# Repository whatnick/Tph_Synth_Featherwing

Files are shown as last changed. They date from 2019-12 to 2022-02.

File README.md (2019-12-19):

# 3-Phase ELV synthesizer using DAC and Opamps

This is a FeatherWing ideally used with Teensy 3.2/4.0 to drive a high-speed DAC with 
filtering and signal conditioning using Opamps.

## Features :
- 50/60 Hz Frequency Selector ( Possibly just do it in software).
- Pot driven voltage Setting by controlling inverting-Opamp gain.
- Modified-Howland current source to simulate current clamp output.
- Pot driven current source using a tapped potentiometer attached to DAC output.
- ±5v RMS output using dual-rail Opamp mode - [OPA4170AIPW](https://au.element14.com/texas-instruments/opa4170aipw/op-amp-quad-rro-1mhz-14tssop/dp/2095843) or [LM324PWR](https://au.element14.com/texas-instruments/lm324pwr/ic-op-amp-1-2mhz-0-5v-us-tssop/dp/2342289)
- Dual-voltage rail generation using [LM2663](https://au.element14.com/texas-instruments/lm2663mx-nopb/dc-dc-charge-pump-inverting-soic/dp/3008264) to flip 5v input to -5v.
- Boost-converter to push battery voltage (4.2v-3.7v) to 5v for non-USB power mode using [PAM2401](https://au.mouser.com/datasheet/2/115/PAM2401-347378.pdf).
- I2C DAC circuit to generate plausible phase shifted sine-wave, like in my [DIYODE 
Article](https://diyodemag.com/features/safe_3-phase_generator) using [MCP4728](https://au.element14.com/microchip/mcp4728-e-un/ic-dac-12bit-quad-10msop/dp/1800217).
- Fully open-source schematic/pcb in KiCAD.
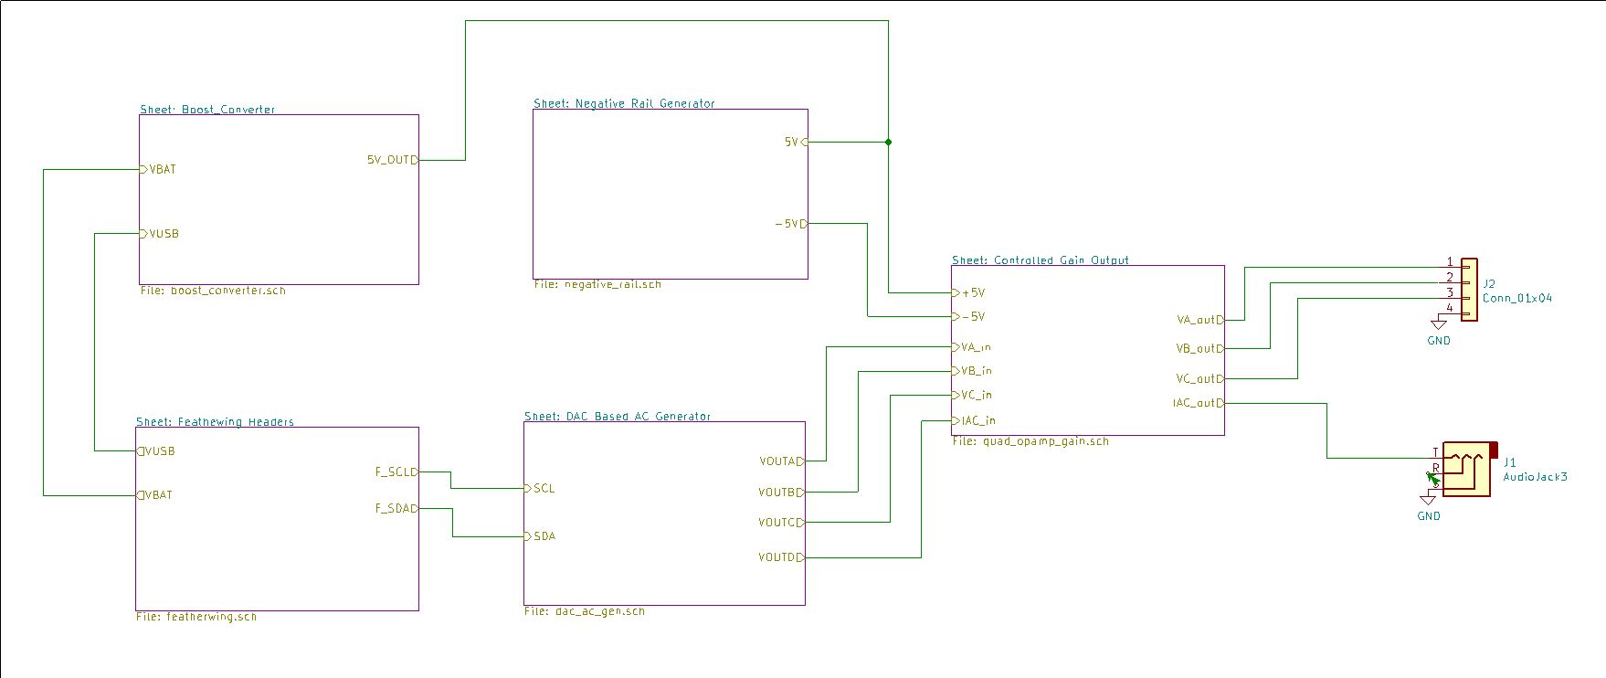
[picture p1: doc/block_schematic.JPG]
Schematic Screenshot


## Roadmap Features :
- Experiment with power Opamps or eBay power amplifiers to output real 240v rail-to-rail swings.
- Experiment with power path IC's to manage supply from USB vs Battery. Particulary [LTC4412](https://www.analog.com/media/en/technical-documentation/data-sheets/4412fb.pdf) is of interest at high-power modes due to losses in [Schottky diodes](https://www.analog.com/media/en/technical-documentation/product-information/Battery_Management_Soulutions_PowerPath.pdf) and LV usage with buck-converters from 240v.
- Add I2C digital pots instead of physical pots.

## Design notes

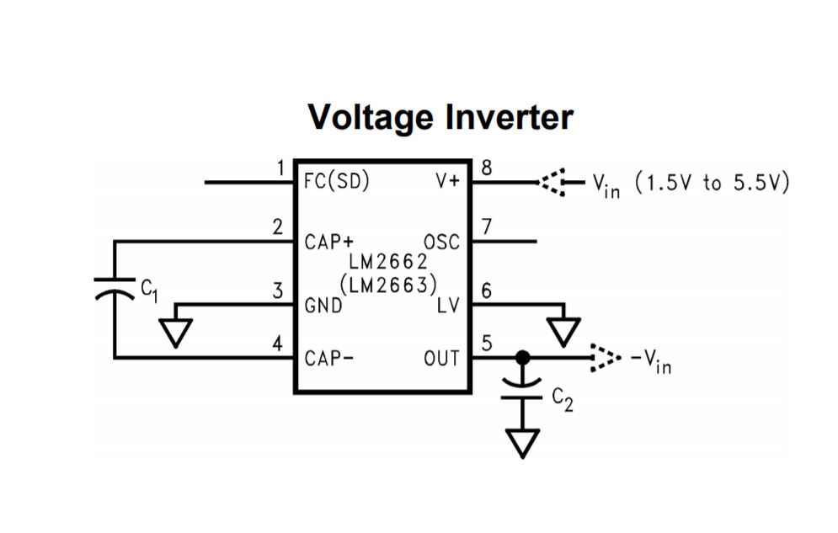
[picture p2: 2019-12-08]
doc/voltage_inverter.JPG

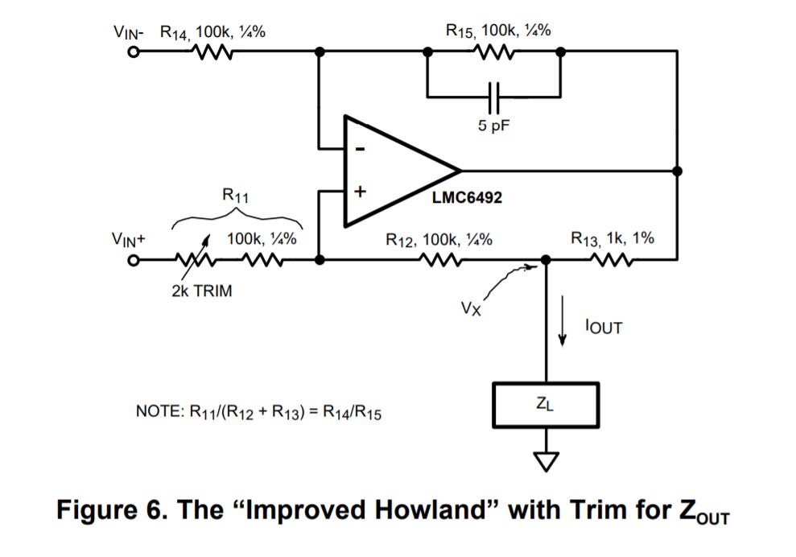
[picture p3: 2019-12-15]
doc/howland_current_pump.JPG

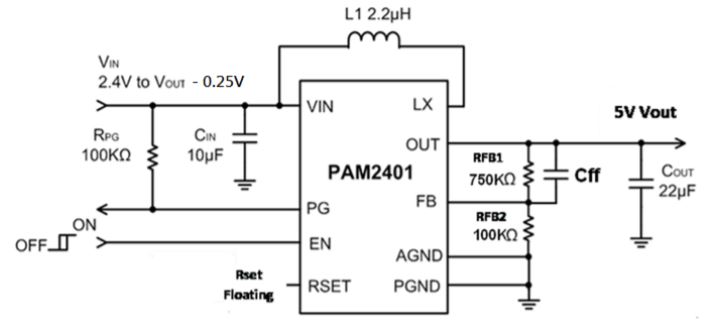
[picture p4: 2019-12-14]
doc/boost_converter.JPG

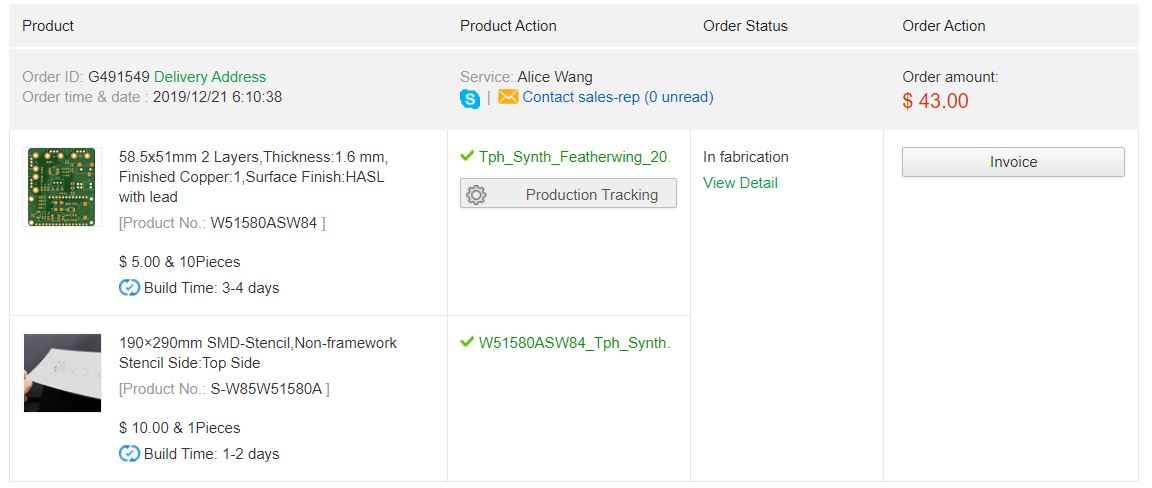
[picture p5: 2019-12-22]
doc/manf_log/pcbway_r0.1.JPG

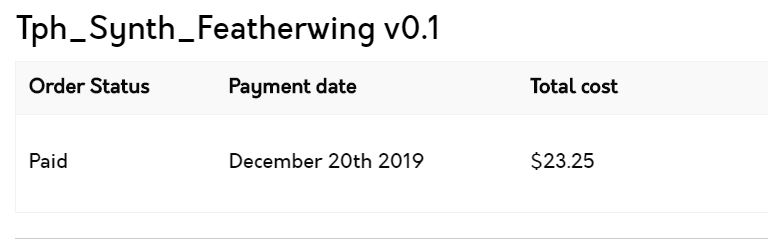
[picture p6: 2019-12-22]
doc/manf_log/oshpark_r0.1.JPG

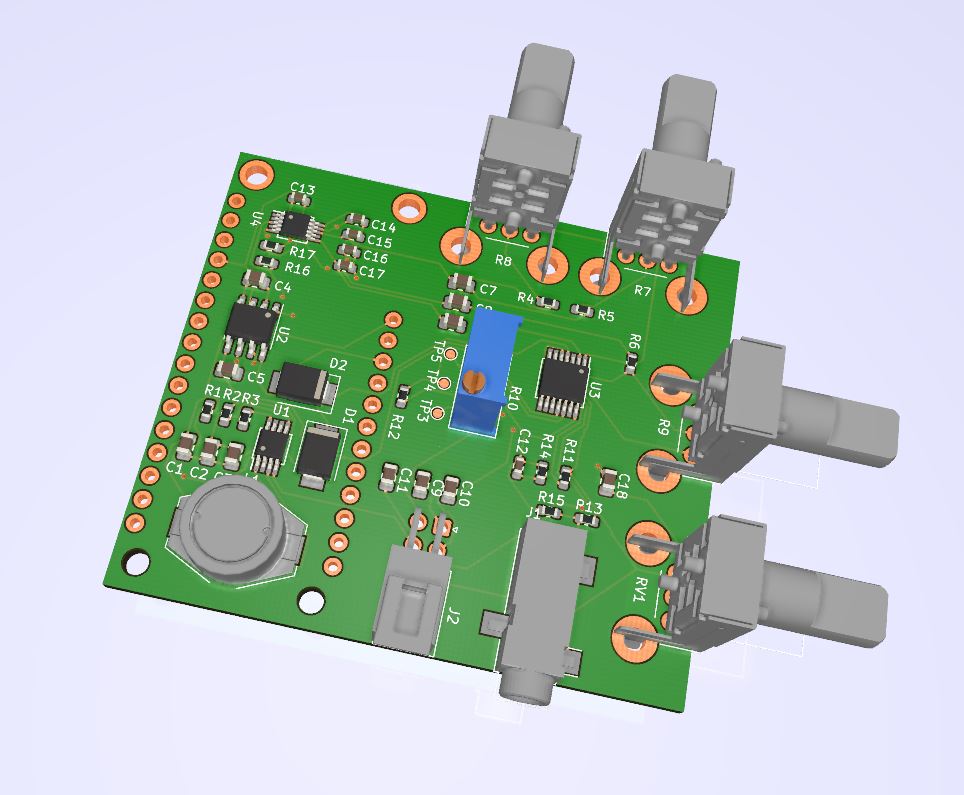
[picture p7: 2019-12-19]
doc/pcb_screenshot.JPG

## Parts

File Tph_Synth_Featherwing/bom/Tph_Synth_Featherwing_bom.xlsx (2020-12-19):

References | manf# | Value | Footprint | Quantity
C1, C2, C3 | C2012JB1V226M125AC | 22u | C_0805_2012Metric | 3
C13, C14, C15, C16, C17 | GCM188L81H104KA57D | 100n | C_0603_1608Metric | 5
C12 | GJM0335C1E5R0BB01D | 5p | C_0603_1608Metric | 1
C4, C5, C6, C7, C8, C9, C10, C11, C18 | GMK212BBJ106MG-T | 10u | C_0805_2012Metric | 9
R15 | CRT0603-FY-1001ELF | 1k / 1% | R_0603_1608Metric | 1
R7, R8, R9 | PTV09A-2020F-B104 | 100k var | Potentiometer_Bourns_PTV09A-2_Single_Horizontal | 3
R10 | PV36W202C01B00 | 2k Trim | Potentiometer_Bourns_3296W_Vertical | 1
R3 | RC0603FR-07100KL | 100k | R_0603_1608Metric | 1
R16, R17 | RC0603FR-072K2L | 2.2k | R_0603_1608Metric | 2
R2 | RC0603FR-07750KL | 750k | R_0603_1608Metric | 1
R11, R12, R13, R14 | RT0603CRE07100KL | 100k / 0.25% | R_0603_1608Metric | 4
R1, R4, R5, R6 | RT0603FRD0710KL | 10k | R_0603_1608Metric | 4
L1 | SRR1005-2R2M | 2.2uH/3A | L_Bourns-SRR1005 | 1
D1, D2 | B330B-13-F | D_Schottky | D_SMB | 2
U2 | LM2663MX/NOPB | LM2663M | SOIC-8_3.9x4.9mm_P1.27mm | 1
U3 | LM324PWR | Opamp_Quad_Generic | TSSOP-14_4.4x5mm_P0.65mm | 1
U4 | MCP4728-E/UN | MCP4728 | MSOP-10_3x3mm_P0.5mm | 1
U1 | PAM2401SCADJ | PAM2401SCADJ | MSOP-8_3x3mm_P0.65mm | 1
MS1 | 3200 | ADAFRUIT_FEATHERWING | adafruit_featherwing | 1
RV1 | PTV09A-2020F-B104 | 100k POT | Potentiometer_Bourns_PTV09A-2_Single_Horizontal | 1
J2 | 105314-1204 | Conn_01x04 | Molex_Nano-Fit_105314-xx04_2x02_P2.50mm_Horizontal | 1
J1 | SJ-3523-SMT-TR | AudioJack3 | Jack_3.5mm_CUI_SJ-3523-SMT_Horizontal | 1
J3 | SM04B-SRSS-TB(LF)(SN) | Conn_01x04 | JST_SH_SM04B-SRSS-TB_1x04-1MP_P1.00mm_Horizontal | 1

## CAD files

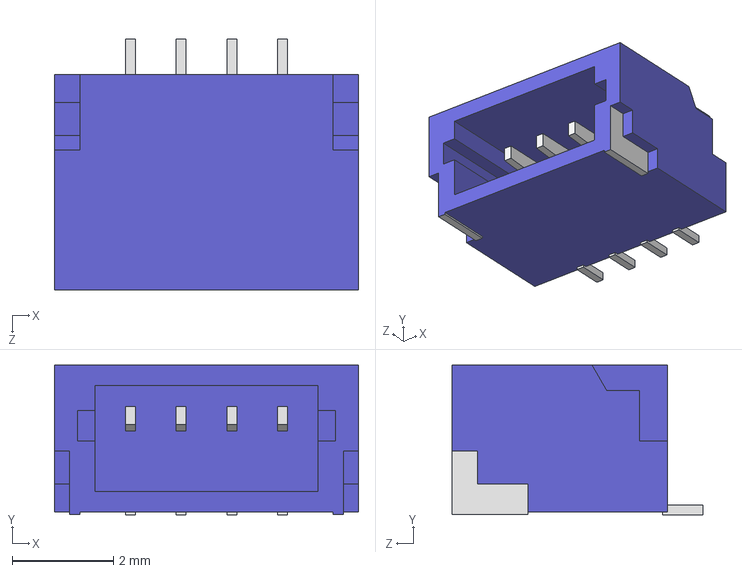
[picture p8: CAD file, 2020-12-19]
Tph_Synth_Featherwing/3dmodels/SM04B-SRSS-TB.STEP
6.00 x 2.96 x 4.95 mm

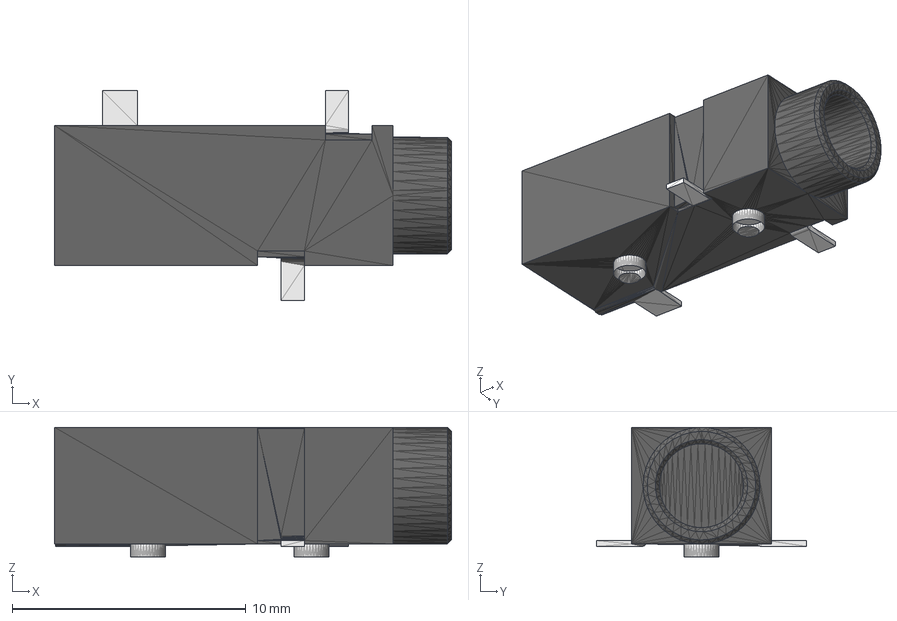
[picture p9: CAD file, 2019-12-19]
Tph_Synth_Featherwing/3dmodels/CUI_SJ-3523.step
17.0 x 9.00 x 5.80 mm

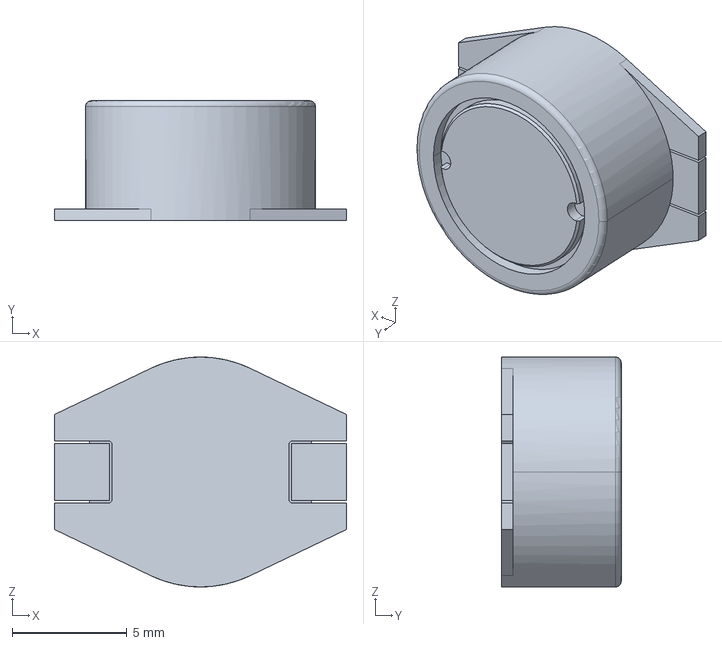
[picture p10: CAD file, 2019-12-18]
Tph_Synth_Featherwing/3dmodels/srr1005.stp
12.7 x 5.20 x 10.0 mm

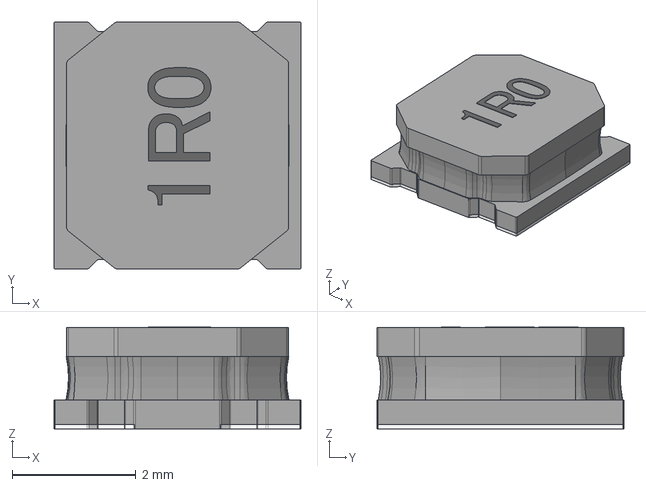
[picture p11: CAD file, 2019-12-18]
Tph_Synth_Featherwing/3dmodels/srn4018.stp
4.00 x 4.00 x 1.65 mm

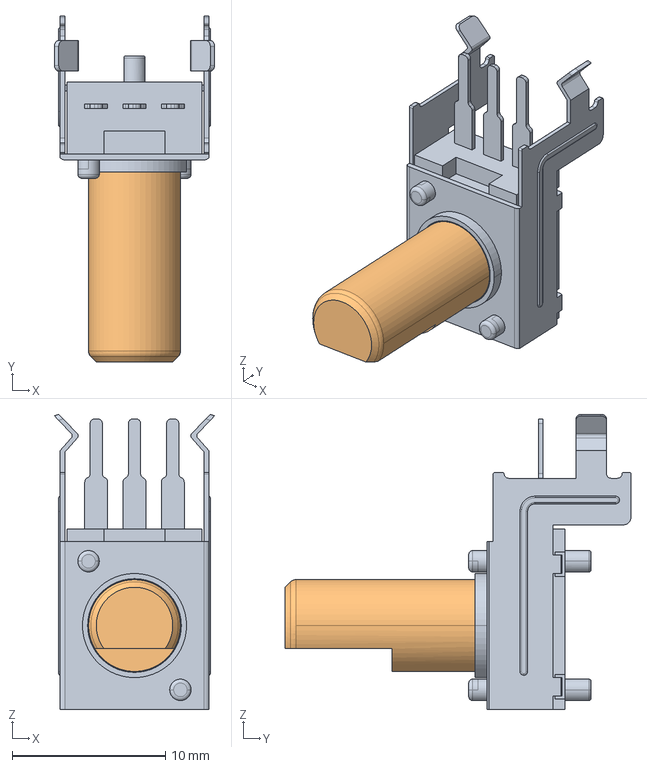
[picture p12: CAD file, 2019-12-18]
Tph_Synth_Featherwing/3dmodels/ptv09a-2x20f-xxxx.stp
10.5 x 22.6 x 19.3 mm

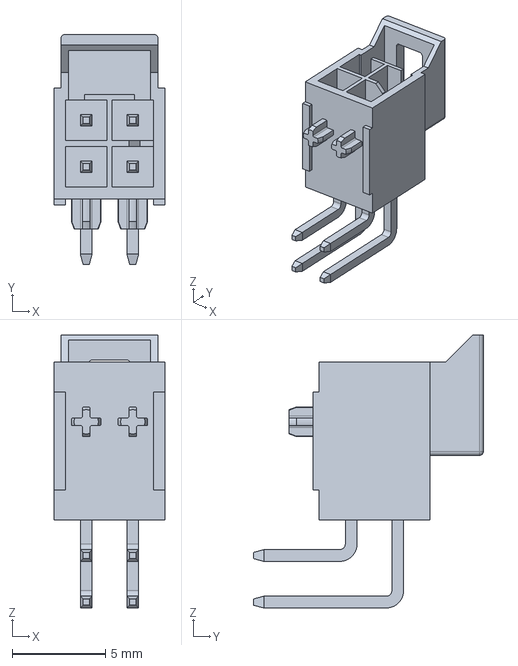
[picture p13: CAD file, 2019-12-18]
Tph_Synth_Featherwing/3dmodels/1053141204.stp
5.94 x 12.3 x 14.7 mm

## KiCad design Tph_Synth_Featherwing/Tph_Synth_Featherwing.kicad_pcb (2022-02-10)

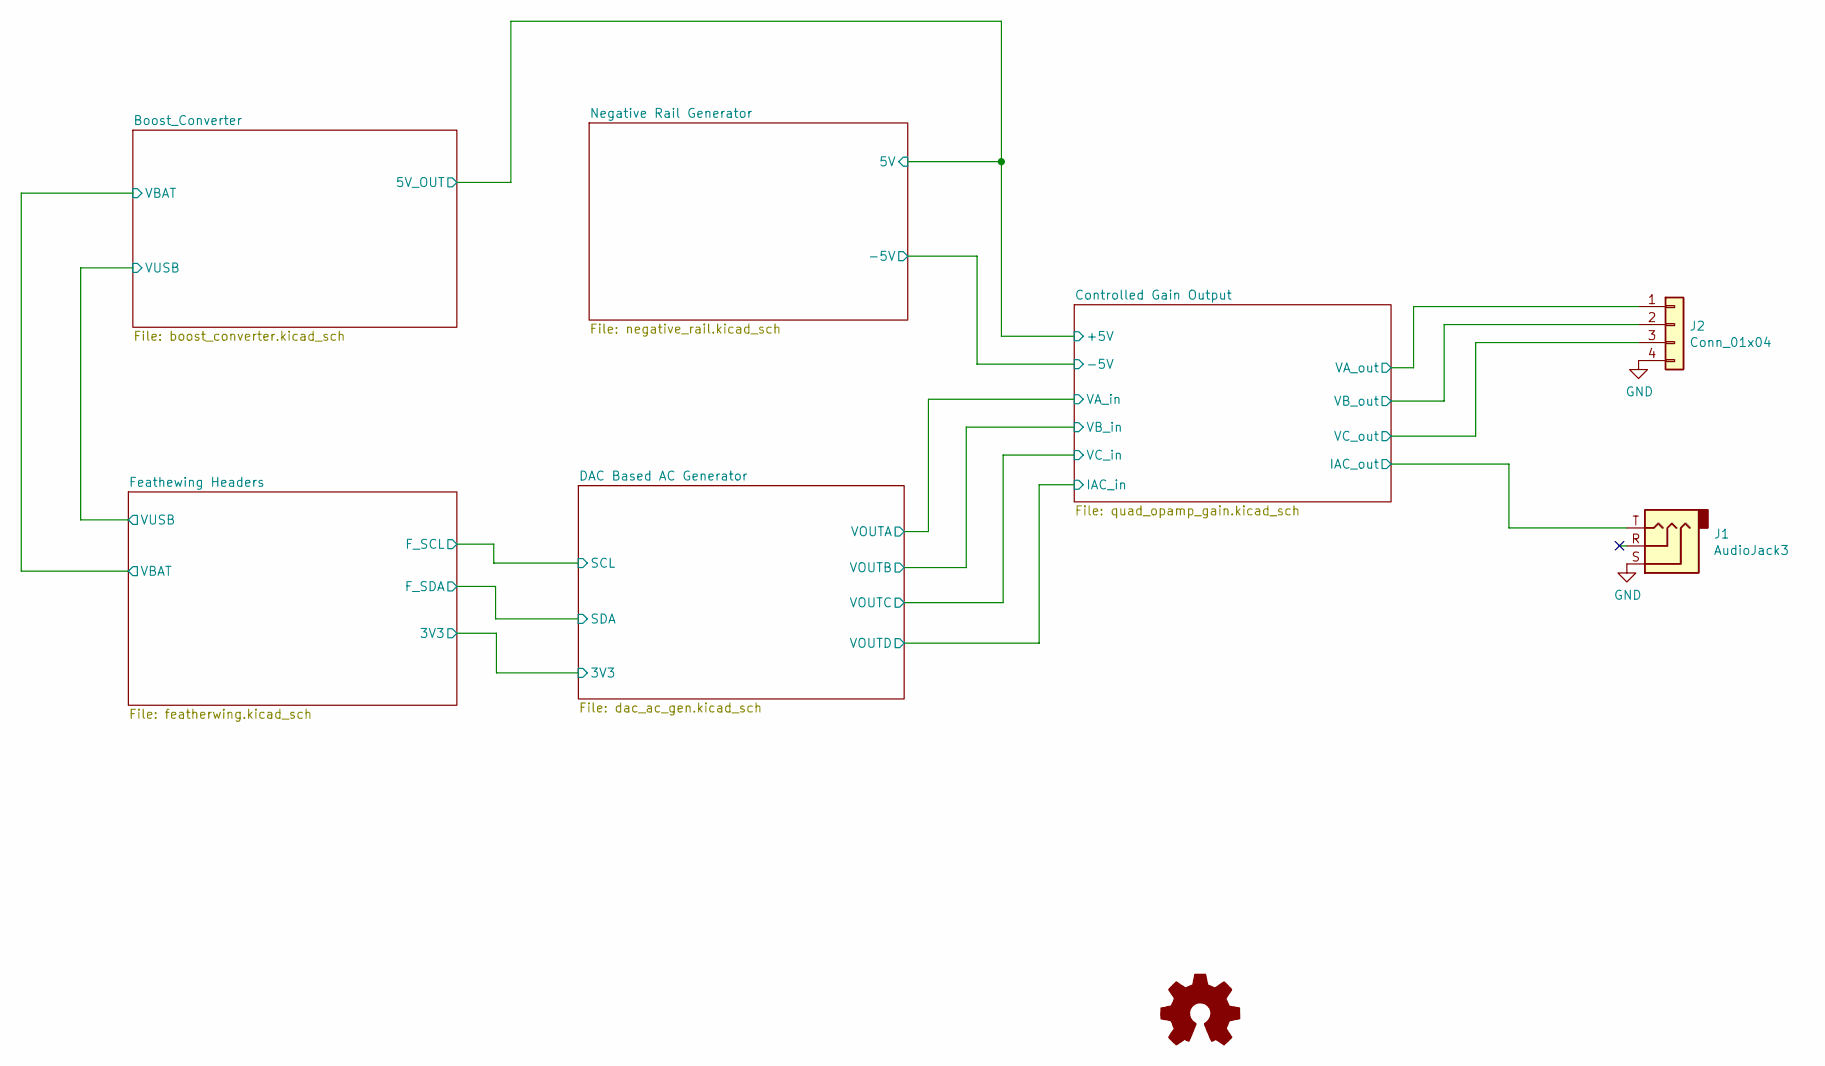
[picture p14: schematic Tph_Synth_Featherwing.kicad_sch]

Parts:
J1: AudioJack3; Jack_3.5mm_CUI_SJ-3523-SMT_Horizontal
J2: Conn_01x04; Molex_Nano-Fit_105314-xx04_2x02_P2.50mm_Horizontal
LOGO1: Logo_Open_Hardware_Small; OSHW-Logo2_7.3x6mm_SilkScreen

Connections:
/IAC_out: J1.T; also elsewhere on the board
/VA_out: J2.1; also elsewhere on the board
/VB_out: J2.2; also elsewhere on the board
/VC_out: J2.3; also elsewhere on the board
GND: J1.S, J2.4; also elsewhere on the board

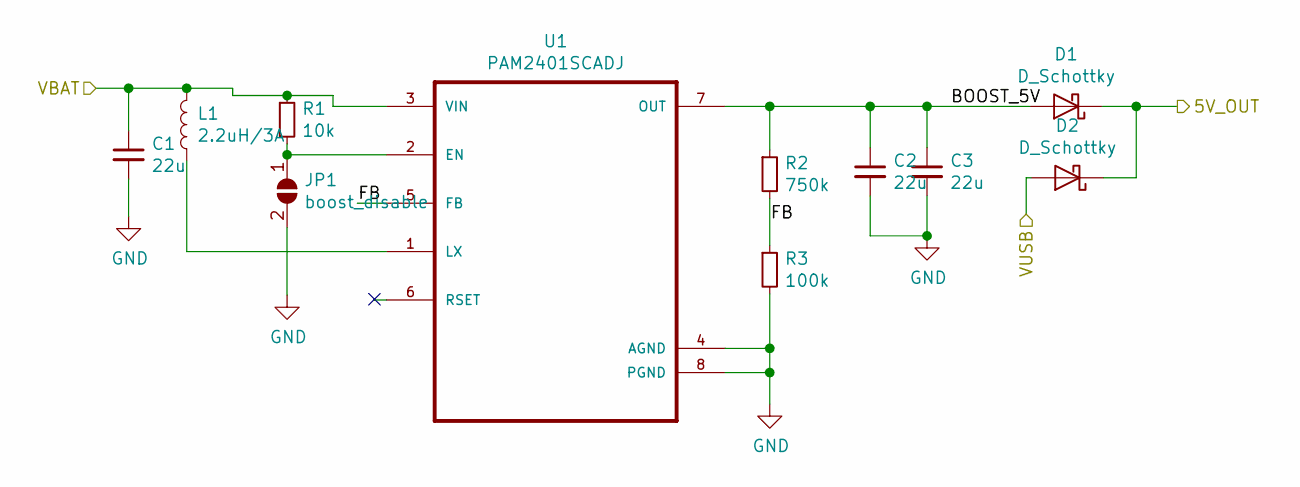
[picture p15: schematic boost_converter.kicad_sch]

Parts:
C1, C2, C3: 22u; C_0805_2012Metric
D1, D2: D_Schottky; D_SMB
JP1: boost_disable; SolderJumper-2_P1.3mm_Open_TrianglePad1.0x1.5mm
L1: 2.2uH/3A; L_Bourns-SRR1005
R1: 10k; R_0603_1608Metric
R2: 750k; R_0603_1608Metric
R3: 100k; R_0603_1608Metric
U1: PAM2401SCADJ; MSOP-8_3x3mm_P0.65mm

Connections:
+5V: D1.1 (K), D2.1 (K); also elsewhere on the board
/Boost_Converter/BOOST_5V: C2.1, C3.1, D1.2 (A), R2.1, U1.7 (OUT)
/Boost_Converter/FB: R2.2, R3.1, U1.5 (FB)
/VBAT: C1.1, L1.2, R1.1, U1.3 (VIN); also elsewhere on the board
/VUSB: D2.2 (A); also elsewhere on the board
GND: C1.2, C2.2, C3.2, JP1.2 (B), R3.2, U1.4 (AGND), U1.8 (PGND); also elsewhere on the board
unnamed: JP1.1 (A), R1.2, U1.2 (EN)
unnamed: L1.1, U1.1 (LX)

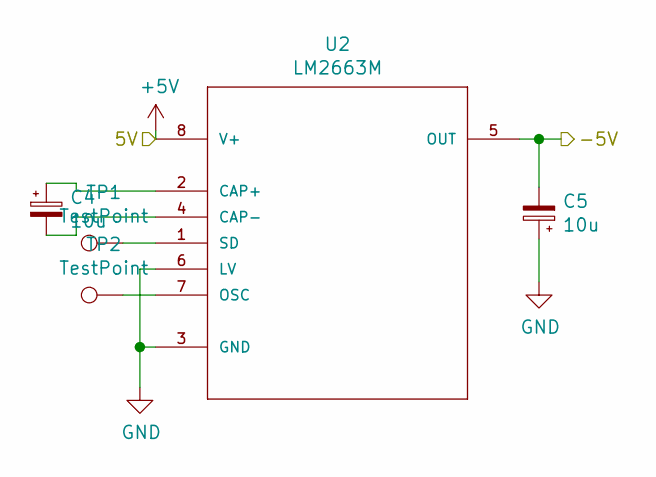
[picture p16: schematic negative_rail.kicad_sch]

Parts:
C4, C5: 10u; C_0805_2012Metric
TP1, TP2: TestPoint; TestPoint_Pad_D1.0mm
U2: LM2663M; SOIC-8_3.9x4.9mm_P1.27mm

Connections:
+5V: U2.8 (V+); also elsewhere on the board
/-5V: C5.2, U2.5 (OUT); also elsewhere on the board
GND: C5.1, U2.3 (GND), U2.6 (LV); also elsewhere on the board
unnamed: C4.1, U2.2 (CAP+)
unnamed: C4.2, U2.4 (CAP-)
unnamed: TP1.1, U2.1 (SD)
unnamed: TP2.1, U2.7 (OSC)

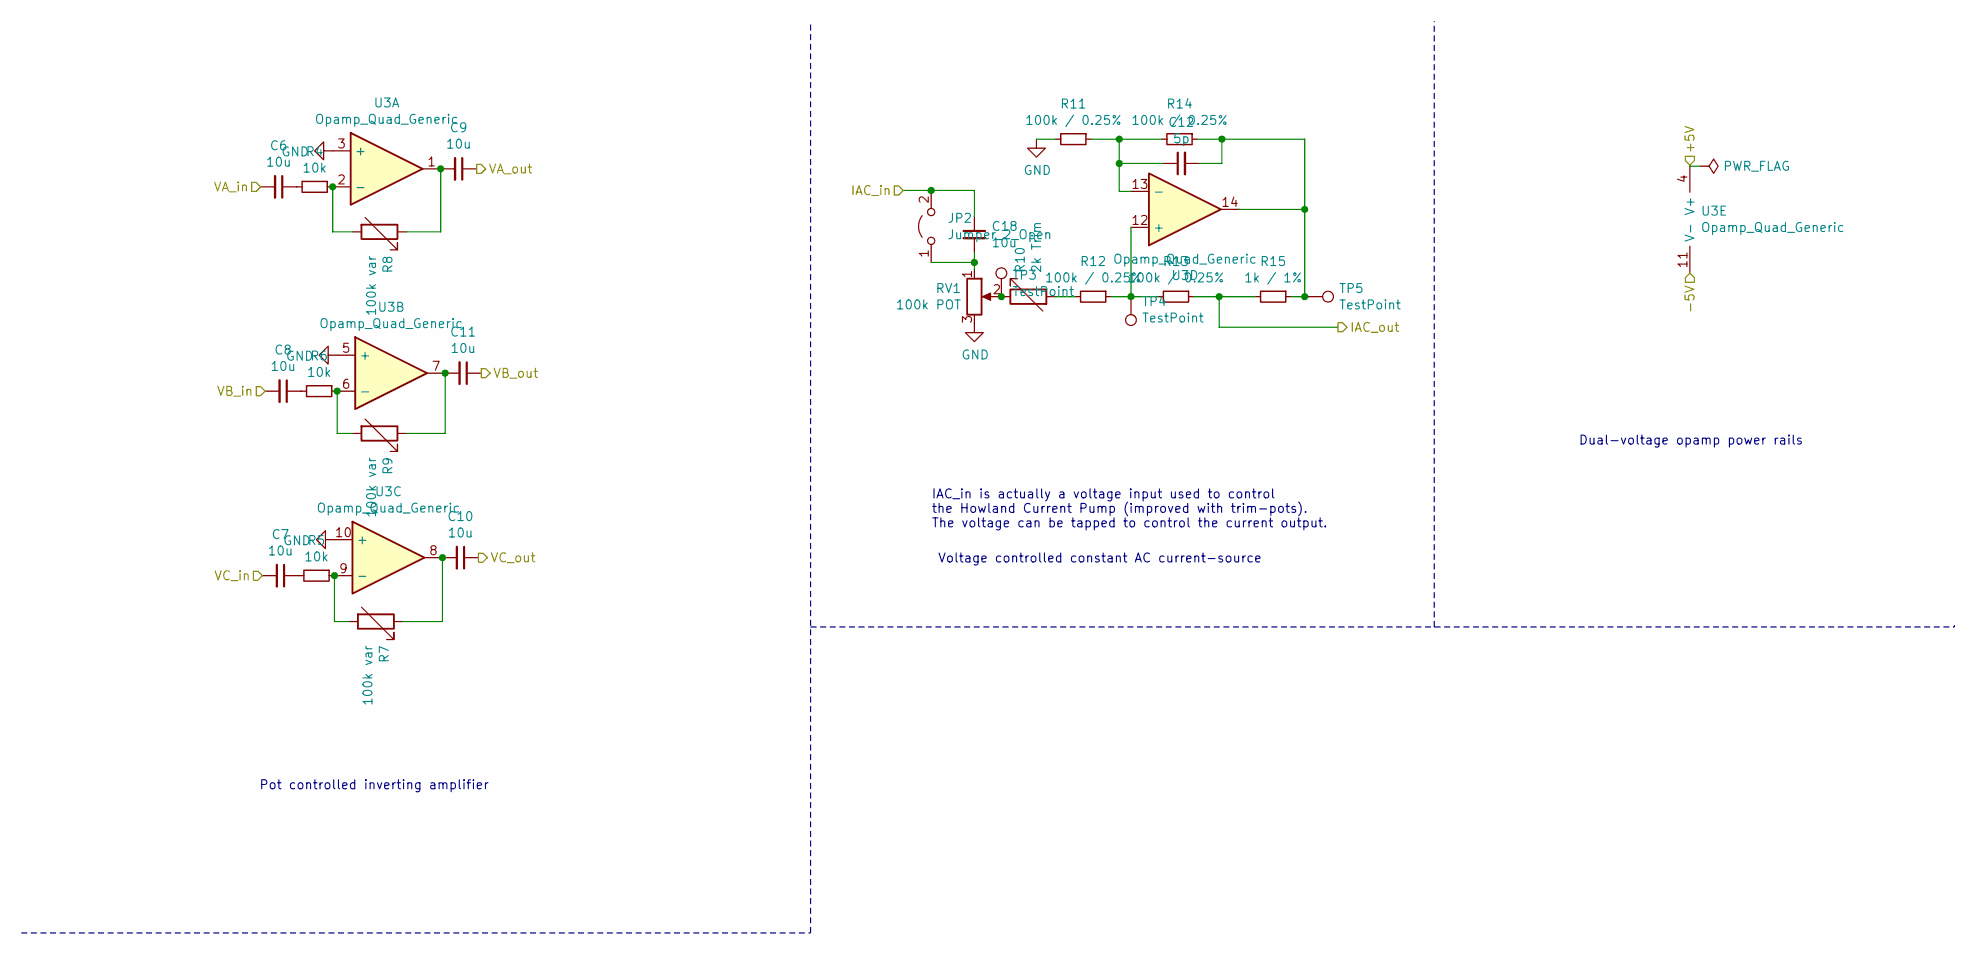
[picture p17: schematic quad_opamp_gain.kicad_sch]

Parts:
C6, C7, C8, C9, C10, C11, C18: 10u; C_0805_2012Metric
C12: 5p; C_0603_1608Metric
JP2: Jumper_2_Open; SolderJumper-2_P1.3mm_Open_TrianglePad1.0x1.5mm
R4, R5, R6: 10k; R_0603_1608Metric
R7, R8, R9: 100k var; Potentiometer_Bourns_PTV09A-2_Single_Horizontal
R10: 2k Trim; Potentiometer_Bourns_3296W_Vertical
R11, R12, R13, R14: 100k / 0.25%; R_0603_1608Metric
R15: 1k / 1%; R_0603_1608Metric
RV1: 100k POT; Potentiometer_Bourns_PTV09A-2_Single_Horizontal
TP3, TP4, TP5: TestPoint; TestPoint_Pad_D1.0mm
U3: Opamp_Quad_Generic; TSSOP-14_4.4x5mm_P0.65mm

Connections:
+5V: U3.4 (V+); also elsewhere on the board
/-5V: U3.11 (V-); also elsewhere on the board
/IAC_out: R13.1, R15.2; also elsewhere on the board
/VA_out: C9.1; also elsewhere on the board
/VB_out: C11.1; also elsewhere on the board
/VC_out: C10.1; also elsewhere on the board
/VOUTA: C6.2; also elsewhere on the board
/VOUTB: C8.2; also elsewhere on the board
/VOUTC: C7.2; also elsewhere on the board
/VOUTD: C18.1, JP2.2 (B); also elsewhere on the board
GND: R11.2, RV1.3, U3.3 (+), U3.5 (+), U3.10 (+); also elsewhere on the board
unnamed: C6.1, R4.2
unnamed: C7.1, R5.2
unnamed: C8.1, R6.2
unnamed: C9.2, R8.1, U3.1
unnamed: C10.2, R7.1, U3.8
unnamed: C11.2, R9.1, U3.7
unnamed: C12.1, R11.1, R14.2, U3.13 (-)
unnamed: C12.2, R14.1, R15.1, TP5.1, U3.14
unnamed: C18.2, JP2.1 (A), RV1.1
unnamed: R4.1, R8.2, U3.2 (-)
unnamed: R5.1, R7.2, U3.9 (-)
unnamed: R6.1, R9.2, U3.6 (-)
unnamed: R10.1, RV1.2, TP3.1
unnamed: R10.2, R12.2
unnamed: R12.1, R13.2, TP4.1, U3.12 (+)

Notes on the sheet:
Voltage controlled constant AC current-source
Pot controlled inverting amplifier
IAC_in is actually a voltage input used to control the Howland Current Pump (improved with trim-pots). The voltage can be tapped to control the current output.
Dual-voltage opamp power rails

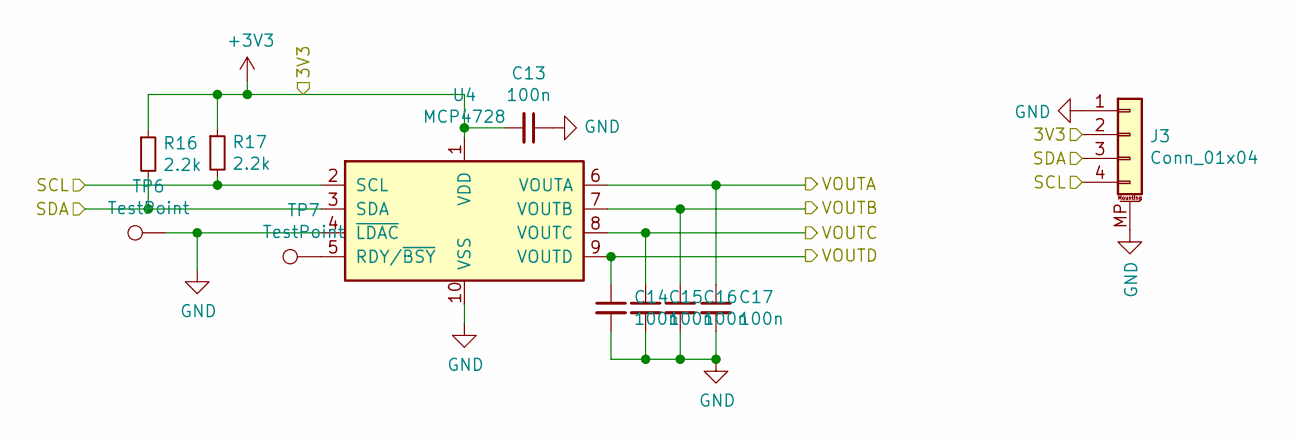
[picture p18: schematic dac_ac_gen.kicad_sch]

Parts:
C13, C14, C15, C16, C17: 100n; C_0603_1608Metric
J3: Conn_01x04; JST_SH_SM04B-SRSS-TB_1x04-1MP_P1.00mm_Horizontal
R16, R17: 2.2k; R_0603_1608Metric
TP6, TP7: TestPoint; TestPoint_Pad_D1.0mm
U4: MCP4728; MSOP-10_3x3mm_P0.5mm

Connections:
+3V3: C13.2, J3.2, R16.1, R17.1, U4.1 (VDD); also elsewhere on the board
/F_SCL: J3.4, R17.2, U4.2 (SCL); also elsewhere on the board
/F_SDA: J3.3, R16.2, U4.3 (SDA); also elsewhere on the board
/VOUTA: C17.1, U4.6 (VOUTA); also elsewhere on the board
/VOUTB: C16.1, U4.7 (VOUTB); also elsewhere on the board
/VOUTC: C15.1, U4.8 (VOUTC); also elsewhere on the board
/VOUTD: C14.1, U4.9 (VOUTD); also elsewhere on the board
GND: C13.1, C14.2, C15.2, C16.2, C17.2, J3.1, J3.MP (MountPin), TP6.1, U4.4 (~LDAC), U4.10 (VSS); also elsewhere on the board
unnamed: TP7.1, U4.5 (RDY/~BSY)

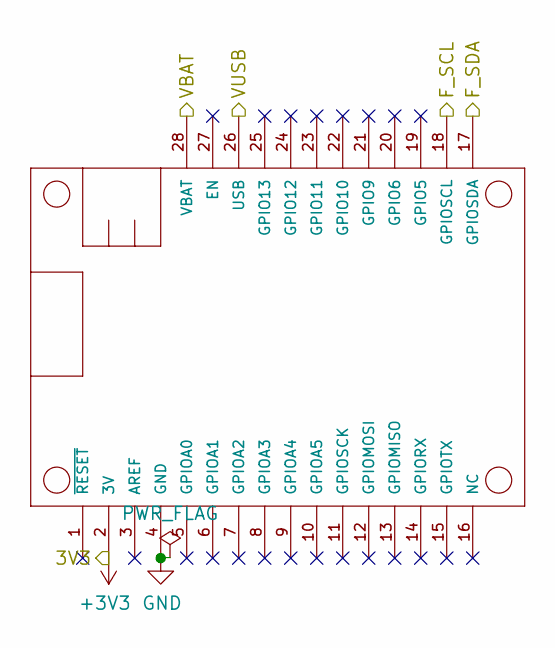
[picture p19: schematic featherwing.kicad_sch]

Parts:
MS1: ADAFRUIT_FEATHERWING; adafruit_featherwing

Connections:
+3V3: MS1.2 (3V); also elsewhere on the board
/F_SCL: MS1.18 (GPIOSCL); also elsewhere on the board
/F_SDA: MS1.17 (GPIOSDA); also elsewhere on the board
/VBAT: MS1.28 (VBAT); also elsewhere on the board
/VUSB: MS1.26 (USB); also elsewhere on the board
GND: MS1.4 (GND); also elsewhere on the board

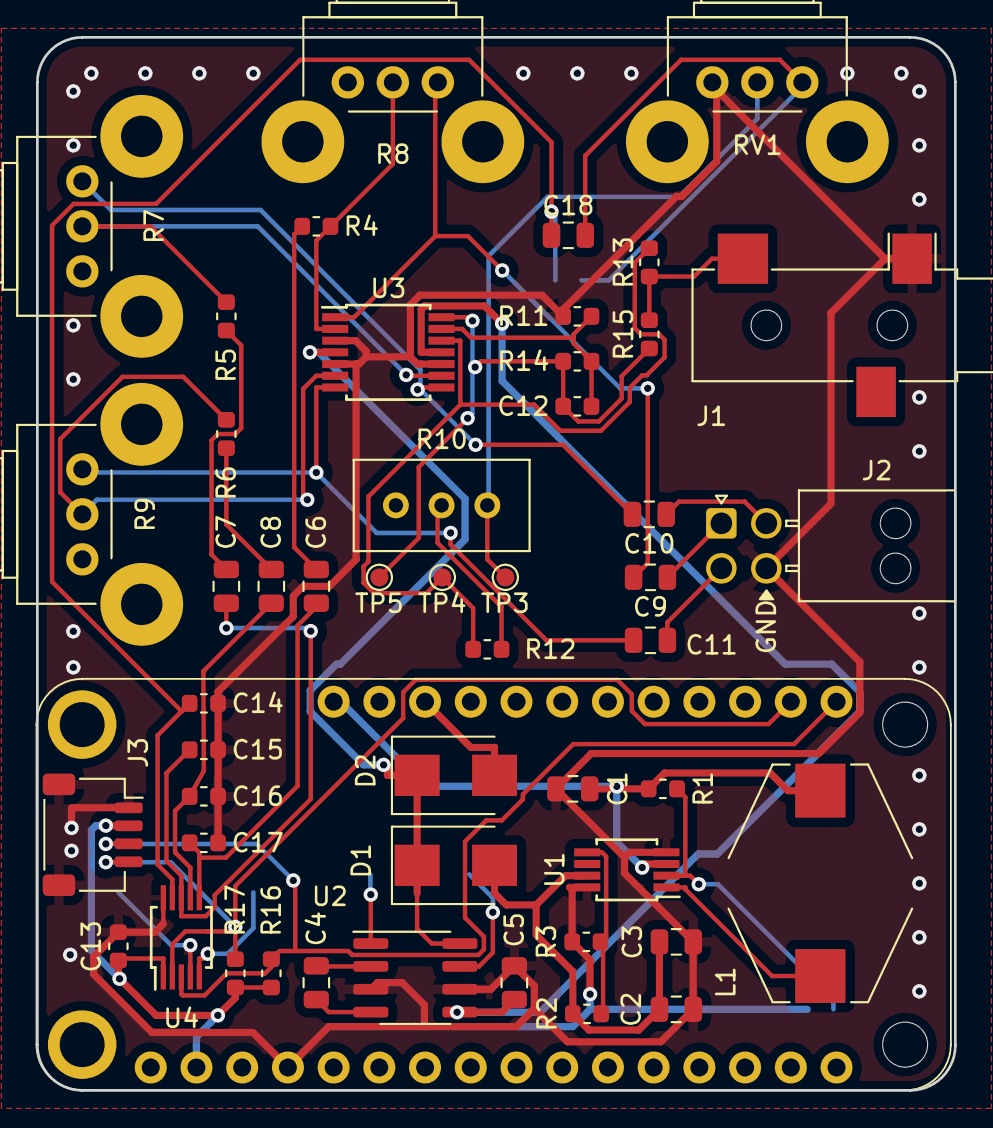
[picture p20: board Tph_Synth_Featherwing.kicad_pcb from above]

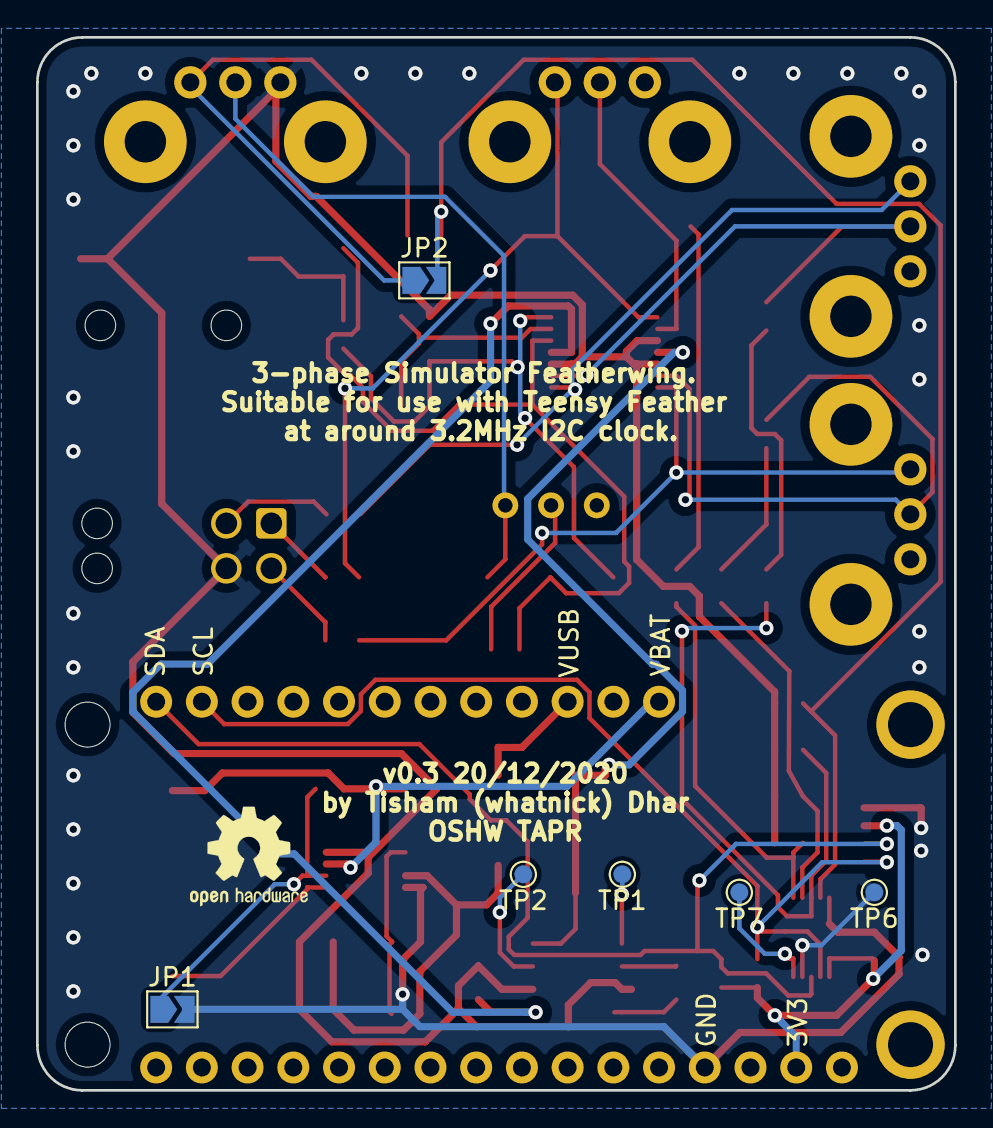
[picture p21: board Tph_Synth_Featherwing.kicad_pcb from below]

Board: 2 copper layers, 51.0 x 58.5 mm, 57 parts (7 on the bottom side), 40 nets.

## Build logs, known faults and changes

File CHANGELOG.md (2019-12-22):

# CHANGELOG

## Initial Part Selection (2019-11-13)
- DAC - 
[MCP4728](https://au.element14.com/microchip/mcp4728-e-un/ic-dac-12bit-quad-10msop/dp/1800217)
- Quad Opamp - 
[OPA4170AIPW](https://au.element14.com/texas-instruments/opa4170aipw/op-amp-quad-rro-1mhz-14tssop/dp/2095843)
- Negative Rail Generator - 
[LM2663](https://au.element14.com/texas-instruments/lm2663mx-nopb/dc-dc-charge-pump-inverting-soic/dp/3008264)

## Battery to 5V boost converter (2019-12-16)
- Added boost converter -
[PAM2401](https://au.mouser.com/datasheet/2/115/PAM2401-347378.pdf)

## AC Constant Current source (2019-12-17)
- Uses spare opamp of Quad-opamp package in [modified-Howland current pump](http://www.ti.com/lit/an/snoa474a/snoa474a.pdf) mode.

## Perform parts search and footprint assignment (2019-12-17)
- Use 3A Schottky diodes [B330B-13-F](https://au.mouser.com/ProductDetail/Diodes-Incorporated/B330B-13-F?qs=cOsaT%252BRvuElEdEmWP6m3Zg%3D%3D) in SMB package.
- Use 2.2uH fixed inductor for Murata [LQH44PH2R2MPRL](https://au.mouser.com/ProductDetail/Murata-Electronics/LQH44PH2R2MPRL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) or Bourns [SRN5020TA-2R2M](https://au.mouser.com/ProductDetail/Bourns/SRN5020TA-2R2M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)
- The Howland current pump needs a trim pot, use an SMD version [PVG5A202C03R00](https://au.mouser.com/ProductDetail/Bourns/PVG5A202C03R00?qs=sGAEpiMZZMvygUB3GLcD7qR9snKKmVdvJfukCFXNzPo%3D) or cheapest THT version [PV36W202C01B00](https://au.mouser.com/ProductDetail/Bourns/PV36W202C01B00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)
- Use linear rotaty pots for gain control pending feedback - [PTV09A-2020F-B104](https://au.mouser.com/ProductDetail/Bourns/PTV09A-2020F-B104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)

## Update L for 3A (2019-12-19)
- Initial choice had 3A as saturation current instead of operating current [SRR1005-2R2M](https://www.digikey.com/product-detail/en/bourns-inc/SRR1005-2R2M/SRR1005-2R2MTRTR-ND/419242).
- Perform initial placement. Group functional blocks together and add missing 3D parts from manufacturer in the 3dmodels directory.
- Do a prelim auto-route to spot placment errors and check routing feasibility.

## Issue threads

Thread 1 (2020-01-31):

Wire DAC to 3.3v

whatnick, 2020-01-31:
Due to signal labelling DAC is not wired to 3.3v rail. Fix this.

Closed 2020-02-01.

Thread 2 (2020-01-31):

Tie LDAC to ground

whatnick, 2020-01-31:
To put the DAC in continuous conversion mode the LDAC pin has to be tied to ground. It is currently floating.

Closed 2020-02-01.

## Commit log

2019-11-13 Initial Hierarchial sheets
    [Tph_Synth_Featherwing.kicad_pcb, Tph_Synth_Featherwing.sch, boost_converter.sch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]
2019-11-13 Initial part selection and Changelog
    [Tph_Synth_Featherwing.sch, boost_converter.sch, dac_ac_gen.sch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]
2019-11-13 Add LM2663 Negative voltage generator
    [negative_rail.sch]
2019-12-08 Add parts for DAC
    [Tph_Synth_Featherwing.sch, boost_converter.sch, dac_ac_gen.sch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]
2019-12-08 Add parts for voltage inverter
    [Tph_Synth_Featherwing.sch, featherwing.sch, negative_rail.sch]
2019-12-14 Progress on sub-sheet labels and boost converter
    [Tph_Synth_Featherwing.sch, boost_converter.sch, dac_ac_gen.sch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]
2019-12-15 Boost-converter and inverting opamps
    [Tph_Synth_Featherwing.sch, boost_converter.sch, dac_ac_gen.sch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]
2019-12-15 Added first-cut of schematic
    [Tph_Synth_Featherwing.sch, boost_converter.sch, dac_ac_gen.sch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]
2019-12-16 240v is technically LV
2019-12-17 Initial attempt at PCB
    [Tph_Synth_Featherwing.sch, boost_converter.sch, dac_ac_gen.sch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]
2019-12-18 Initial cut at part placement
    [1053141204.stp, CUI_SJ-3523.step, Tph_Synth_Featherwing.kicad_pcb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]
2019-12-18 Note Inductor parts choice
    [boost_converter.sch]
2019-12-19 Pre-lim autoroute and renders
    [Tph_Synth_Featherwing.dsn, Tph_Synth_Featherwing.kicad_pcb, quad_opamp_gain.sch]
2019-12-19 More don't trust the autorouter
    [Tph_Synth_Featherwing.dsn, Tph_Synth_Featherwing.kicad_pcb, boost_converter.sch]
2019-12-19 Change 3D model colour, rounded corners
    [CUI_SJ-3523.step, Tph_Synth_Featherwing.kicad_pcb]
2019-12-20 Added ground pour and stitching vias
    [Tph_Synth_Featherwing.kicad_pcb]
2019-12-20 New renders with ground pour
2019-12-20 Add blurb silk screen
    [Tph_Synth_Featherwing.kicad_pcb, Tph_Synth_Featherwing.sch]
2019-12-20 Add PCB measurements
    [Tph_Synth_Featherwing.kicad_pcb]
2019-12-20 Add gerbers for v0.1
    [Tph_Synth_Featherwing-B.Cu.gbl, Tph_Synth_Featherwing-B.Mask.gbs, Tph_Synth_Featherwing-B.Paste.gbp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]
2019-12-22 Added BOM and upgraded to kicad 5.0
    [Tph_Synth_Featherwing.kicad_pcb, Tph_Synth_Featherwing.sch, boost_converter.sch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]
2019-12-22 Add Excel BOM for quick upload to suppliers
    [Tph_Synth_Featherwing_bom.xlsx]
2020-02-01 #1 and #2 add mising wiring
    [Tph_Synth_Featherwing.kicad_pcb, Tph_Synth_Featherwing.sch, dac_ac_gen.sch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]
2020-02-01 #1 and #2 Generate new gerbers and bom
    [Tph_Synth_Featherwing-B_Cu.gbl, Tph_Synth_Featherwing-B_Mask.gbs, Tph_Synth_Featherwing-B_Paste.gbp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]
2020-02-01 Clean up old gerbers
    [Tph_Synth_Featherwing-B.Cu.gbl, Tph_Synth_Featherwing-B.Mask.gbs, Tph_Synth_Featherwing-B.Paste.gbp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]
2020-12-19 Migrate to KiCAD nightly
    [Tph_Synth_Featherwing.kicad_pcb, Tph_Synth_Featherwing.kicad_sch, Tph_Synth_Featherwing.sch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]
2020-12-19 Fix silk screens
    [Tph_Synth_Featherwing.kicad_pcb]
2020-12-19 Add Qwiic connector to design
    [SM04B-SRSS-TB.STEP, Tph_Synth_Featherwing.kicad_pcb, Tph_Synth_Featherwing.kicad_sch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]
2020-12-19 Improve/update silk screen
    [Tph_Synth_Featherwing.kicad_pcb, dac_ac_gen.kicad_sch, featherwing.kicad_sch]
2020-12-19 New gerbers
    [Tph_Synth_Featherwing-B_Cu.gbl, Tph_Synth_Featherwing-B_Mask.gbs, Tph_Synth_Featherwing-B_Paste.gbp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]
2020-12-19 Update Excel BOM
    [Tph_Synth_Featherwing_bom.xlsx]
2022-02-10 Upgrade to kicad 6
    [Tph_Synth_Featherwing.kicad_pcb, Tph_Synth_Featherwing.kicad_sch, boost_converter.kicad_sch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]
2026-10-28 Upgrade design to KiCad 10; clear ERC and DRC violations
2026-10-28 Release v0.4 with complete KiCad 10 schematic-PCB parity
    Synchronize pad nets, schematic paths, component fields and BOM exclusions while retaining routing and placement. Restore project-local STEP models, fix edge silkscreen using local footprint variants, update revision metadata and improve schematic readability. Include inspected PDF and PCB renders.
2026-11-07 Manufacturing prep, sourcing, pot fit, turntable and Elecrow quote (#6)
    Includes #5 (silkscreen labels, closes #3; checked manufacturing package) and:
    - Live Mouser/DigiKey/JLC sourcing evidence; 13 approved breakout capacitor substitutions.
    - Factory DNP for Feather host headers.
    - PTV09 panel-pot STEP offset fix; PV36W (R10) pitch/pin check, 0.8 vs 0.9 mm hole flag.
    - Populated-STEP Blender turntable and render script.
    - Regenerated v0.4 manufacturing package; unpaid Elecrow bare-PCB quote record.
    Closes #3
